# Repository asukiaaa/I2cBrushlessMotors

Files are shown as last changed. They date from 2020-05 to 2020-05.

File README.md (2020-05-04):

# I2cBrushlessMotors-PCB

# Components

- [n-ch mosfet SOT23 GSD](http://akizukidenshi.com/catalog/g/gI-06049/)
- [p-ch mosfet SOT23 GSD](http://akizukidenshi.com/catalog/g/gI-02553/)
- Connector: [digikey](https://www.digikey.jp/product-detail/ja/molex/0530480310/WM1743-ND/242865), [aliexpress](https://ja.aliexpress.com/item/33051652575.html?spm=a2g0s.9042311.0.0.1b2f4c4dqTyiXp)
- [Diode SOD-123FL](http://akizukidenshi.com/catalog/g/gI-06014/)
- [Doide SOD-323](http://akizukidenshi.com/catalog/g/gI-07687/)

# References

- [Racerstar BR0603C 0603 17000KV 19000KV 22000KV 1S Blue FPV Racing Brushless Motor - 19000KV](https://m.racerstar.com/racerstar-br0603c-0603-17000kv-19000kv-22000kv-1s-blue-fpv-racing-brushless-motor-19000kv-p-279.html)
- [4PCS Racerstar & MAMBA 08028 1S 16000KV Brushless Motor 1.0mm Shaft With SH1.25 3PIN For FPV Racing Drone](https://m.racerstar.com/4pcs-racerstar-and-mamba-08028-1s-16000kv-brushless-motor-1_0mm-shaft-with-sh1_25-3pin-for-fpv-racing-drone-p-334.html)

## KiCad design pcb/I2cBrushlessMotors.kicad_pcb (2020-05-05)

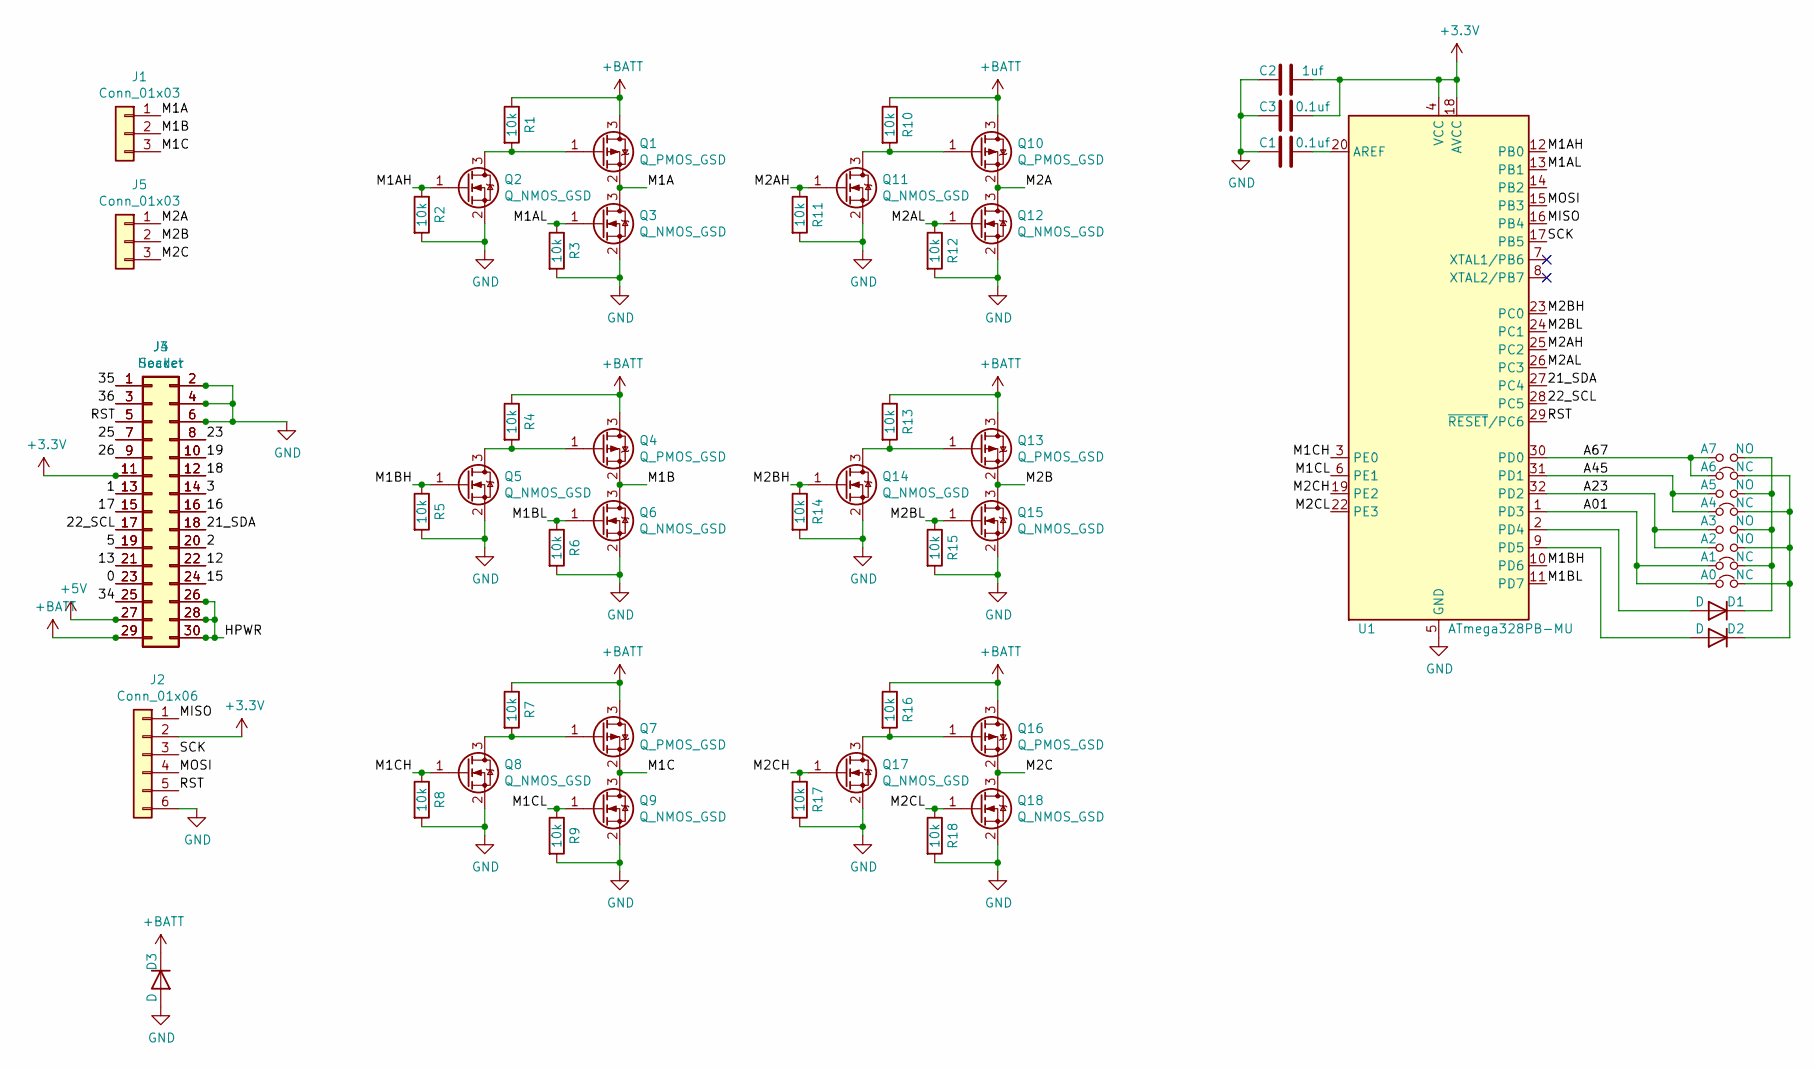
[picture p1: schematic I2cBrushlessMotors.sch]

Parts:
A0, A1, A4, A6: NC; SolderJumper-2_P1.3mm_Bridged_RoundedPad1.0x1.5mm
A2, A3, A5, A7: NO; SolderJumper-2_P1.3mm_Open_RoundedPad1.0x1.5mm
C1, C3: 0.1uf; C_0603_1608Metric
C2: 1uf; C_0603_1608Metric
D1, D2: D; D_SOD-323
D3: D; D_SOD-123F
J1, J5: Conn_01x03; Molex_1x03_P1.25mm_Vertical
J2: Conn_01x06; 2x03_P2.54mm_Pads
J3: Header; PinHeader_2x15_P2.54mm_M5Stack
J4: Socket; PinSocket_2x15_P2.54mm_Vertical_SMD_just_for_M5Stack_bottom
Q1, Q4, Q7, Q10, Q13, Q16: Q_PMOS_GSD; SOT-23
Q2, Q3, Q5, Q6, Q8, Q9, Q11, Q12, Q14, Q15, Q17, Q18: Q_NMOS_GSD; SOT-23
R1, R2, R3, R4, R5, R6, R7, R8, R9, R10, R11, R12, R13, R14, R15, R16, R17, R18: 10k; R_0603_1608Metric
U1: ATmega328PB-MU; QFN-32-1EP_5x5mm_P0.5mm_EP3.1x3.1mm

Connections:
+3V3: C2.2, C3.2, J2.2, J3.11, J4.11, U1.4 (VCC), U1.18 (AVCC)
+5V: J3.27, J4.27
+BATT: D3.1 (K), J3.29, J4.29, Q1.3 (D), Q4.3 (D), Q7.3 (D), Q10.3 (D), Q13.3 (D), Q16.3 (D), R1.1, R4.1, R7.1, R10.1, R13.1, R16.1
/0: J3.23, J4.23
/1: J3.13, J4.13
/2: J3.20, J4.20
/3: J3.14, J4.14
/5: J3.19, J4.19
/12: J3.22, J4.22
/13: J3.21, J4.21
/15: J3.24, J4.24
/16: J3.16, J4.16
/17: J3.15, J4.15
/18: J3.12, J4.12
/19: J3.10, J4.10
/21_SDA: J3.18, J4.18, U1.27 (PC4)
/22_SCL: J3.17, J4.17, U1.28 (PC5)
/23: J3.8, J4.8
/25: J3.7, J4.7
/26: J3.9, J4.9
/34: J3.25, J4.25
/35: J3.1, J4.1
/36: J3.3, J4.3
/A01: A0.1, A1.1, U1.1 (PD3)
/A23: A2.1, A3.1, U1.32 (PD2)
/A45: A4.1, A5.1, U1.31 (PD1)
/A67: A6.1, A7.1, U1.30 (PD0)
/HPWR: J3.26, J3.28, J3.30, J4.26, J4.28, J4.30
/M1A: J1.1, Q1.2 (S), Q3.3 (D)
/M1AH: Q2.1 (G), R2.1, U1.12 (PB0)
/M1AL: Q3.1 (G), R3.1, U1.13 (PB1)
/M1B: J1.2, Q4.2 (S), Q6.3 (D)
/M1BH: Q5.1 (G), R5.1, U1.10 (PD6)
/M1BL: Q6.1 (G), R6.1, U1.11 (PD7)
/M1C: J1.3, Q7.2 (S), Q9.3 (D)
/M1CH: Q8.1 (G), R8.1, U1.3 (PE0)
/M1CL: Q9.1 (G), R9.1, U1.6 (PE1)
/M2A: J5.1, Q10.2 (S), Q12.3 (D)
/M2AH: Q11.1 (G), R11.1, U1.25 (PC2)
/M2AL: Q12.1 (G), R12.1, U1.26 (PC3)
/M2B: J5.2, Q13.2 (S), Q15.3 (D)
/M2BH: Q14.1 (G), R14.1, U1.23 (PC0)
/M2BL: Q15.1 (G), R15.1, U1.24 (PC1)
/M2C: J5.3, Q16.2 (S), Q18.3 (D)
/M2CH: Q17.1 (G), R17.1, U1.19 (PE2)
/M2CL: Q18.1 (G), R18.1, U1.22 (PE3)
/MISO: J2.1, U1.16 (PB4)
/MOSI: J2.4, U1.15 (PB3)
/RST: J2.5, J3.5, J4.5, U1.29 (~RESET~/PC6)
/SCK: J2.3, U1.17 (PB5)
GND: C1.1, C2.1, C3.1, D3.2 (A), J2.6, J3.2, J3.4, J3.6, J4.2, J4.4, J4.6, Q2.2 (S), Q3.2 (S), Q5.2 (S), Q6.2 (S), Q8.2 (S), Q9.2 (S), Q11.2 (S), Q12.2 (S), Q14.2 (S), Q15.2 (S), Q17.2 (S), Q18.2 (S), R2.2, R3.2, R5.2, R6.2, R8.2, R9.2, R11.2, R12.2, R14.2, R15.2, R17.2, R18.2, U1.5 (GND), U1.21 (GND), U1.33 (GND)
unnamed: A0.2, A2.2, A4.2, A6.2, D2.1 (K)
unnamed: A1.2, A3.2, A5.2, A7.2, D1.1 (K)
unnamed: C1.2, U1.20 (AREF)
unnamed: D1.2 (A), U1.2 (PD4)
unnamed: D2.2 (A), U1.9 (PD5)
unnamed: Q1.1 (G), Q2.3 (D), R1.2
unnamed: Q4.1 (G), Q5.3 (D), R4.2
unnamed: Q7.1 (G), Q8.3 (D), R7.2
unnamed: Q10.1 (G), Q11.3 (D), R10.2
unnamed: Q13.1 (G), Q14.3 (D), R13.2
unnamed: Q16.1 (G), Q17.3 (D), R16.2

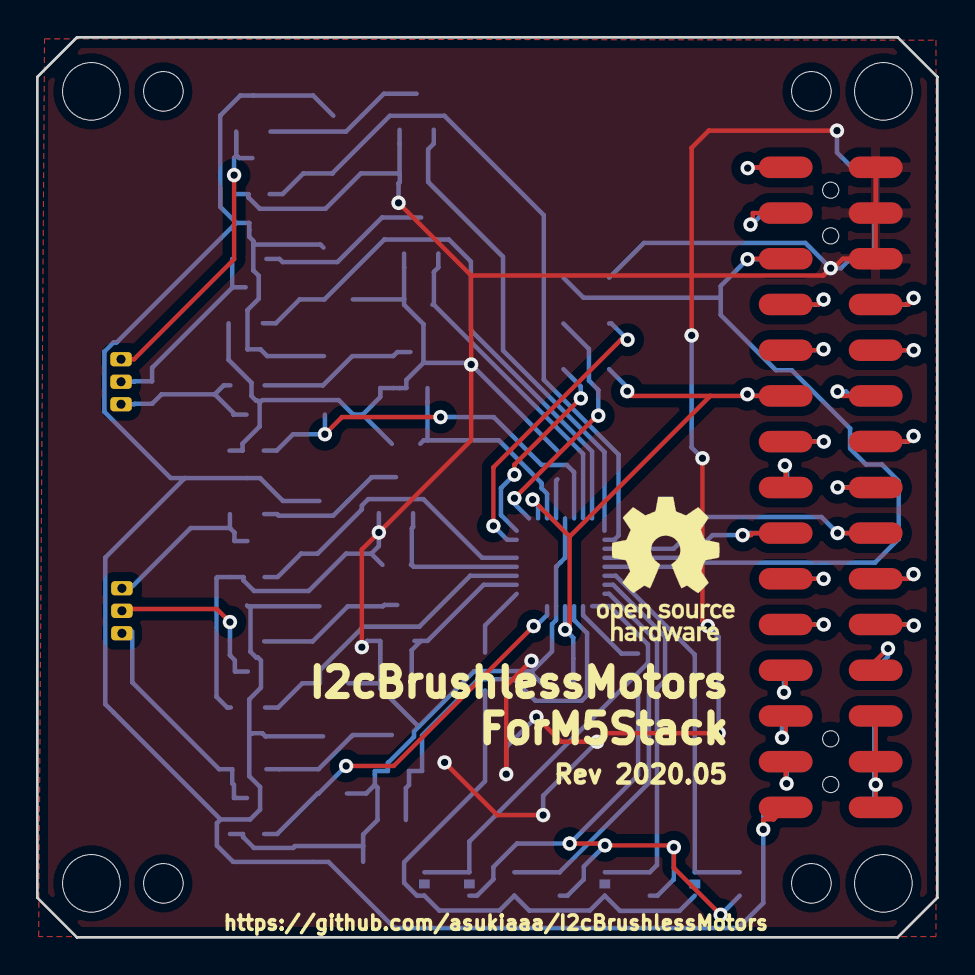
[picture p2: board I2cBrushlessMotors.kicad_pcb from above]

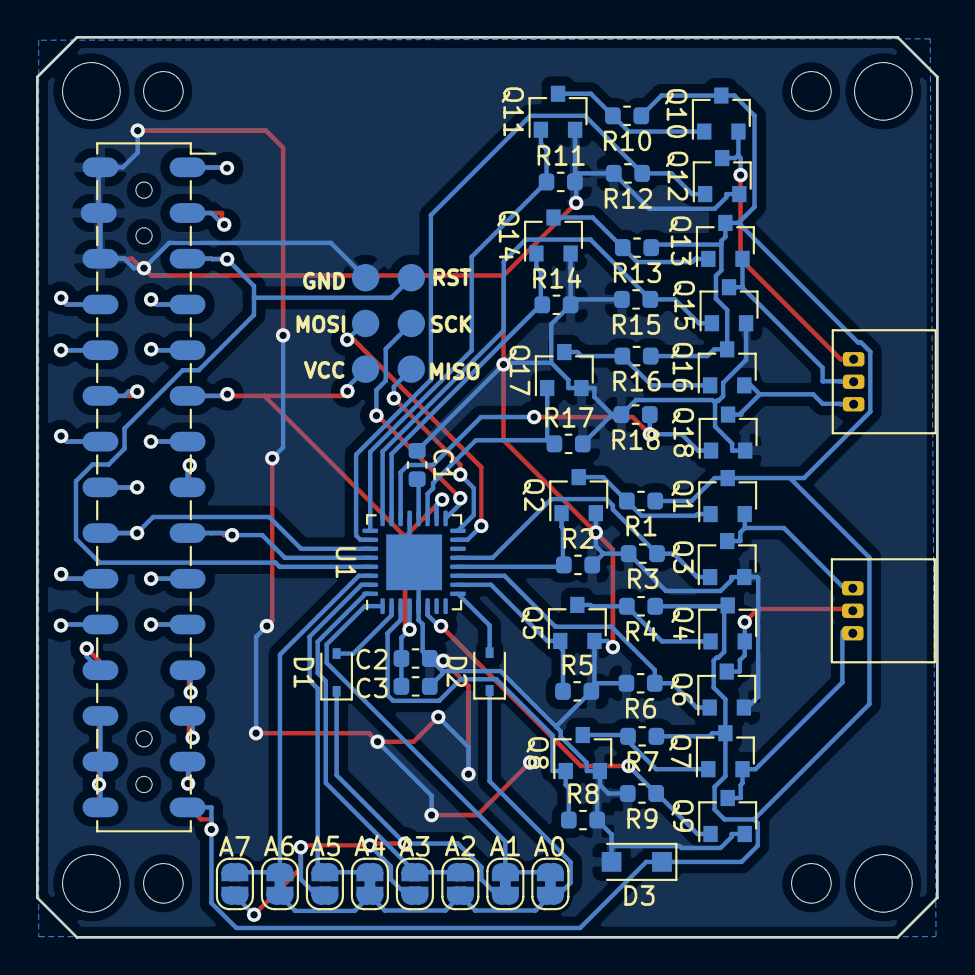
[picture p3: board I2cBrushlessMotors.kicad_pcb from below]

Board: 2 copper layers, 50.0 x 50.0 mm, 64 parts (55 on the bottom side), 62 nets.

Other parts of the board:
REF1, REF4, REF6, REF9: MountingHole_3.2mm_M3
REF2, REF3, REF7, REF8: MountingHole_2.2mm_M2
